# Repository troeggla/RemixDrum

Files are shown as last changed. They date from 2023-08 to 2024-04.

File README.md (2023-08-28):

# RemixDrum 🪄🎵

🇧🇷 Este trabalho apresenta o protótipo do RemixDrum, uma ferramenta criada seguindo o paradigma do design autobiográfico, capaz de combinar sensores, placas microcontroladoras, conexão sem fio e aplicativos personalizados desenvolvidos nas linguagens Pure Data e Processing para remixar trilhas musicais e artes visuais em tempo real. O objetivo final é aguçar o pensamento criativo dos participantes, estimulando a idealização de obras que exploram o hibridismo multimídia.

🇺🇸/🇬🇧 The remix technique has been widely used in musical practice, mainly due to the figure of Disc Jockeys (DJs), which combines several pre-existing sounds to produce completely new content.
However, this creation method also appears in other forms of artistic expression, such as architecture, photography, fashion design, video games, etc.
Recent technological advances favor the emergence of gadgets that help expand this practice, such as Smart Musical Instruments (SMI), devices equipped with sensors, actuators, embedded intelligence, and wireless connectivity to allow new forms of musical expression.
In view of this scenario and the versatility of remix, this paper presents a prototype of an SMI, called RemixDrum, conceived not only for creating sounds through technological means but also to allow the mixing of multimedia content, proposing a new context of use for this type of interface and a new way to make art.
Finally, the prototype was evaluated quantitatively, measuring average latency, jitter, and throughput, qualitatively, investigating the user experience and  their interaction with the equipment, and comparatively, through an analysis between our prototype and related works, in order to analyze perceptible delays, expressiveness and other artistic factors.

License: GNU Public License v3

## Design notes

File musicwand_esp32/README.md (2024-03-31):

# RemixDrum ESP32

This directory contains the code for RemixDrum adapted for the ESP32 platform.
More specifically, this code is intended to run on an Seeed Studio XIAO ESP32S3
using port D1 for capacitive touch sensing and an MPU6050 IMU for determining
acceleration and angular rotation.

Note that this project is intended to be compiled using the
[PlatformIO](https://platformio.org/) extension for Visual Studio code.

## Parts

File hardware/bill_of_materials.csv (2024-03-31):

Name | Designator | Description
HDR-M-2.54_1x1 | J1 | Single pin header
JST-PH-2P | J2 | JST Battery connector
SEEED XIAO ESP32S3 | U1 | ESP32 microcontroller
MPU6050 | U2 | MPU6050 IMU module

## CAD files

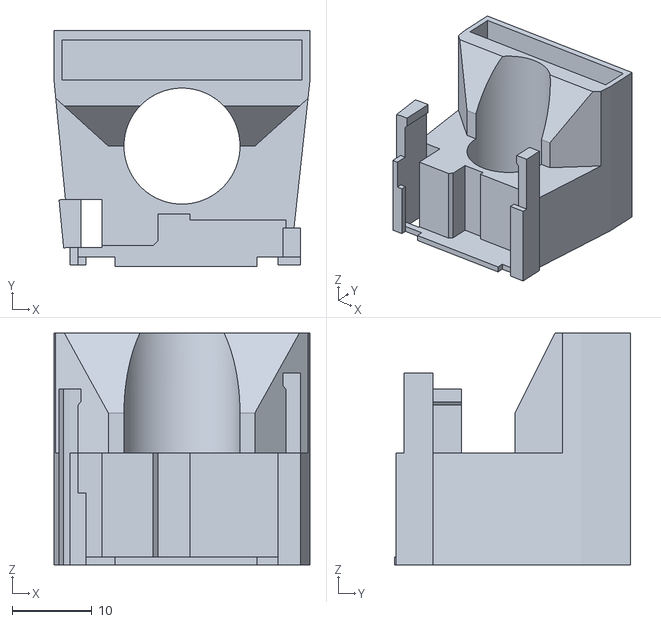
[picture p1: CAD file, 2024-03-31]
hardware/remixdrum_case.stl
32.0 x 29.5 x 29.0

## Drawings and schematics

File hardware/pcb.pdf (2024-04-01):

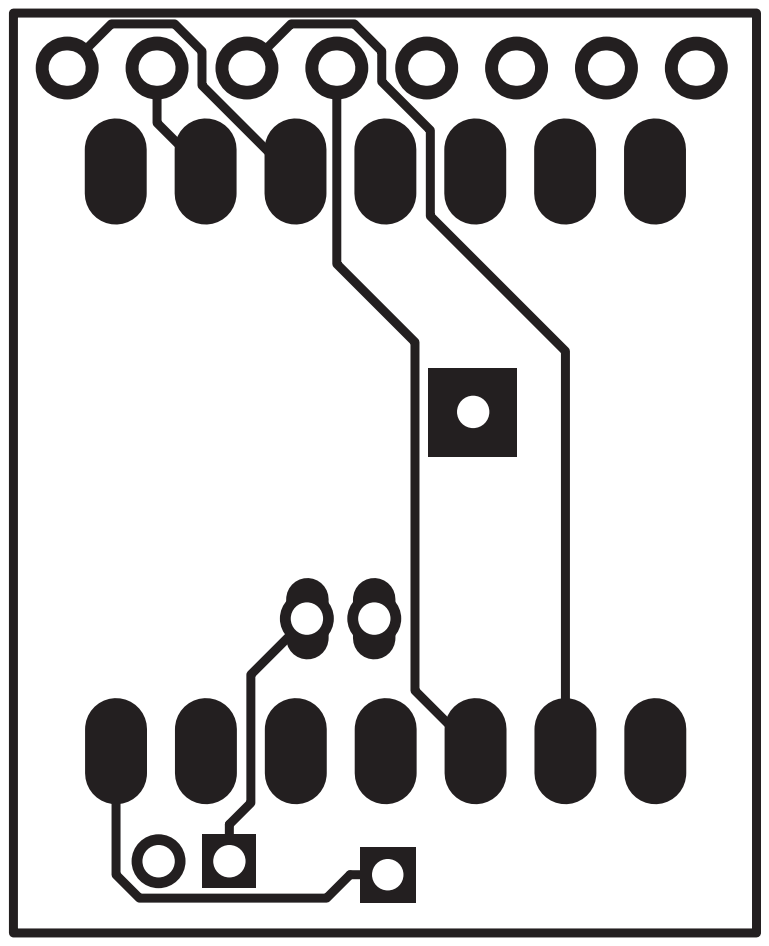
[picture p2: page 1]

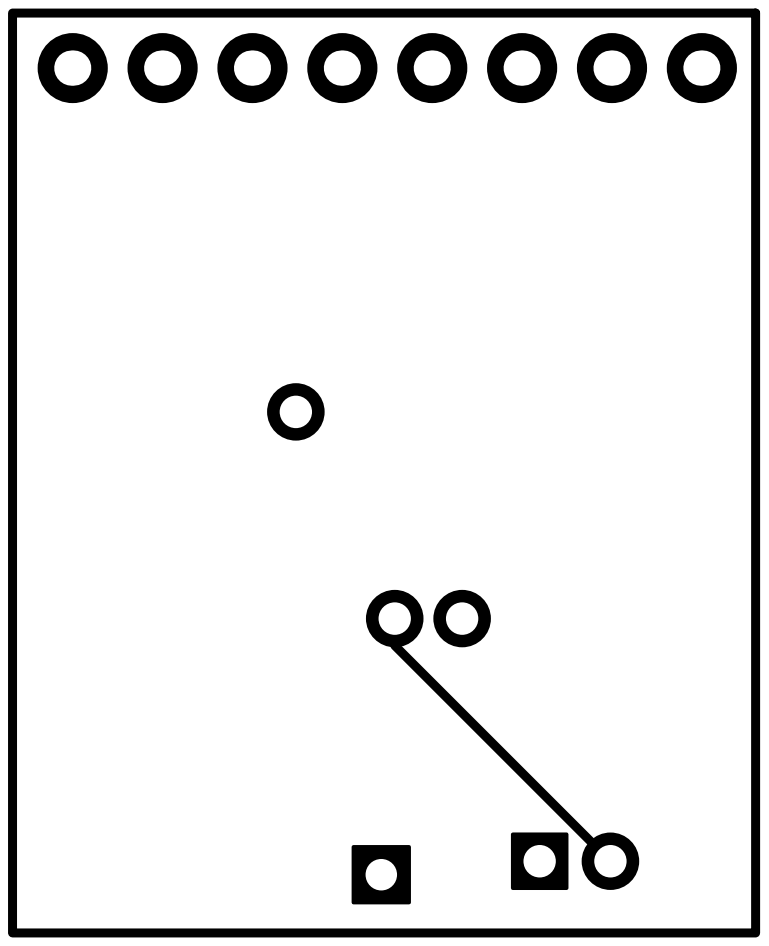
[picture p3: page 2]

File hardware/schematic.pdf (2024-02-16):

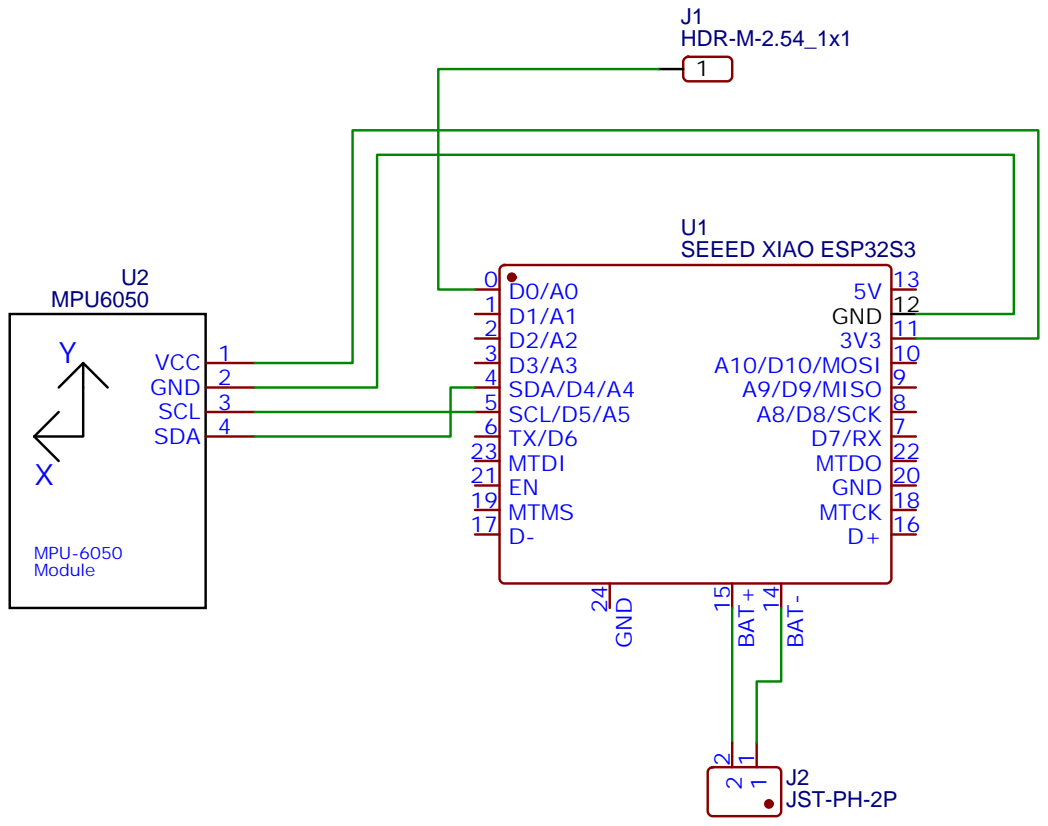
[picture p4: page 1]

Drawn By: Thomas Roeggla

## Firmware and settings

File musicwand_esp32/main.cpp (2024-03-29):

/*
Music Wand
Created by: Rômulo Vieira, Célio Albuquerque & Débora Muchaluat-Saade
Fluminense Federal University (UFF) - Brazil
Updated by: Thomas Röggla
Centrum Wiskunde & Informatica (CWI) - Netherlands
GNU General Public License v3

Buy me a coffee --> paypal: romulo_vieira96@yahoo.com.br
*/
#include <WiFi.h>

#include "classes/capacitive_touch_pad.hpp"
#include "classes/imu.hpp"
#include "classes/osc_endpoint.hpp"

// SSID and password for WiFi
#define WIFI_SSID "Romulo" // EDIT: Network name
#define WIFI_PASS "romulo182" // EDIT: Network password

// Constants
#define TOUCH_PIN D0 // Touch sensor pin (D0 pin on ESP32)
#define MPU_ADDRESS 0x68 // I2C address for the MPU6050 accelerometer

// Port definitions
#define PURE_DATA_PORT 9999
#define PROCESSING_PORT 7777
#define LOCAL_PORT 2390

// UDP socket
WiFiUDP socket;

// OSC endpoints
OSCEndpoint pureDataEndPoint(socket, PURE_DATA_PORT);
OSCEndpoint processingEndPoint(socket, PROCESSING_PORT);

// IMU
IMU imu(MPU_ADDRESS);

// Capacitive touch pad
CapacitiveTouchPad touchPad(TOUCH_PIN);

void setup() {
  // Baud Rate
  Serial.begin(115200);

  // Connecting to Wi-Fi Network
  Serial.print("Connecting to ");
  Serial.print(WIFI_SSID);
  Serial.println(" ");

  WiFi.begin(WIFI_SSID, WIFI_PASS);

  while (WiFi.status() != WL_CONNECTED) {
    delay(500);
    Serial.print(".");
  }

  Serial.println();

  Serial.println("WiFi connected!");
  Serial.print("IP address: ");
  Serial.println(WiFi.localIP());

  Serial.println("Starting UDP");
  socket.begin(LOCAL_PORT);

  // Initialise IMU
  imu.begin();
}

void loop() {
  // Touch sensor logic
  int padIsTouched = touchPad.isTouched(); // Reading the touch sensor
  Serial.print(padIsTouched); // Print touch sensor in serial monitor

  // Get reading from accelerometer
  imu.measureAccel();

  // Send X axis to serial monitor
  Serial.print(" | GyX = ");
  Serial.print(imu.getAccelX());
  // Send Y axis to serial monitor
  Serial.print(" | GyY = ");
  Serial.print(imu.getAccelY());
  // Send Z axis to serial monitor
  Serial.print(" | GyZ = ");
  Serial.println(imu.getAccelZ());

  // Send touch sensor message to the client with OSC protocol
  pureDataEndPoint.sendMessage("/value", padIsTouched);

  // Sending accelerometer X-axis message to Pure Data
  pureDataEndPoint.sendMessage("/gyx", imu.getAccelX());
  // Sending accelerometer X-axis message to Processing
  processingEndPoint.sendMessage("/gyx", imu.getAccelX());

  // Sending accelerometer Y-axis message to Pure Data
  pureDataEndPoint.sendMessage("/gyy", imu.getAccelY());
  // Sending accelerometer Y-axis message to Processing
  processingEndPoint.sendMessage("/gyy", imu.getAccelY());

  // Sending accelerometer Z axis message to Pure Data
  pureDataEndPoint.sendMessage("/gyz", imu.getAccelZ());

  delay(100);
}

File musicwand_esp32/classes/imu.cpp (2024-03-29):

#include "imu.hpp"

void IMU::begin() {
  // Setting MPU6050 accelerometer
  Wire.begin();
  Wire.beginTransmission(address);
  Wire.write(0x6B);

  // Reset the IMU
  Wire.write(0x00);
  Wire.endTransmission(true);
}

void IMU::measureAccel() {
  // Accelerometer MPU6050 logic
  Wire.beginTransmission(address);
  Wire.write(0x3B);
  Wire.endTransmission(false);
  Wire.requestFrom(address, 6, 1); // Reading MPU6050 data (6 bytes)

  // Reading the accelerometer
  int accel_X = Wire.read() << 8 | Wire.read();  //0x3B (ACCEL_XOUT_H) & 0x3C (ACCEL_XOUT_L)
  int accel_Y = Wire.read() << 8 | Wire.read();  //0x3D (ACCEL_YOUT_H) & 0x3E (ACCEL_YOUT_L)
  int accel_Z = Wire.read() << 8 | Wire.read();  //0x3F (ACCEL_ZOUT_H) & 0x40 (ACCEL_ZOUT_L)

  // Change the accelerometer's range (0º to 180º)
  this->accelX = map(accel_X, 0, IMU_MAX, 0, 180);
  this->accelY = map(accel_Y, 0, IMU_MAX, 0, 180);
  this->accelZ = map(accel_Z, 0, IMU_MAX, 0, 180);
}

int IMU::getAccelX() {
  return this->accelX;
}

int IMU::getAccelY() {
  return this->accelY;
}

int IMU::getAccelZ() {
  return this->accelZ;
}

void IMU::measureGyro() {
  // Gyroscope MPU6050 logic
  Wire.beginTransmission(address);
  Wire.write(0x43);
  Wire.endTransmission(false);
  Wire.requestFrom(address, 6, 1); // Reading MPU6050 data (6 bytes)

  // Reading the gyroscope
  int gyro_X = Wire.read() << 8 | Wire.read();  //0x43 (GYRO_XOUT_H) & 0x44 (GYRO_XOUT_L)
  int gyro_Y = Wire.read() << 8 | Wire.read();  //0x45 (GYRO_YOUT_H) & 0x46 (GYRO_YOUT_L)
  int gyro_Z = Wire.read() << 8 | Wire.read();  //0x47 (GYRO_ZOUT_H) & 0x48 (GYRO_ZOUT_L)

  // Change the gyroscope's range (0º to 180º)
  this->gyroX = map(gyro_X, 0, IMU_MAX, 0, 180);
  this->gyroY = map(gyro_Y, 0, IMU_MAX, 0, 180);
  this->gyroZ = map(gyro_Z, 0, IMU_MAX, 0, 180);
}

int IMU::getGyroX() {
  return this->gyroX;
}

int IMU::getGyroY() {
  return this->gyroY;
}

int IMU::getGyroZ() {
  return this->gyroZ;
}

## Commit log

2024-02-09 updated mcu code to work with esp32
2024-02-09 fixed warning in WiFi.requestFrom()
    [main.cpp]
2024-02-09 added capTouchRead function for capacitive touch on builtin pins
2024-02-09 replaced digitalRead() for touch pin with capTouchRead()
    [main.cpp]
2024-02-10 extracted code for reading gyroscope into class
2024-02-12 added audio samples for puredata patch
2024-02-12 updated paths to samples in puredata patch
2024-02-16 added class to abstract reading from a capacitive touch pad
2024-02-16 using CapacitiveTouchPad class for reading from capacitive touch pad
2024-02-16 setting pinMode in constructor of CapacitiveTouchPad
2024-02-16 passing UDP socket into constructor of OSCEndpoint
2024-02-16 constructor for OSCEndpoint now takes reference to socket
2024-02-16 moved delays for I2C transmission and networking into methods
2024-02-16 cleaned up print statements
2024-02-16 added PDF schematic
2024-02-16 moved wireshark packet capture file into separate folder
2024-02-19 renamed gyroscope to accelerometer to better reflect its purpose
2024-02-19 fixed call for resetting the device
    [accelerometer.cpp]
2024-03-29 writing 0x00 to IMU to reset it
    [accelerometer.cpp, main.cpp]
2024-03-29 added methods to read the gyroscope form the IMU
2024-03-29 renamed class Accelerometer to IMU and updated references
2024-03-29 added readme for the arduino project
2024-03-31 moved schematic to folder hardware/
2024-03-31 added bill of materials to hardware folder
    [bill_of_materials.csv]
2024-03-31 added 3D model for case to hardware folder
    [remixdrum_case.stl]
2024-04-01 added PDF file containing pcb
2024-04-01 removed unused pads from pcb top layer
